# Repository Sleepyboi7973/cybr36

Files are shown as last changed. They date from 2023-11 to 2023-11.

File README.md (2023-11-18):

# cybr36
 The cybr36 is a no frills, wireless, 36 key, column-staggered keyboard sporting button cell batteries and nice!nano controllers.

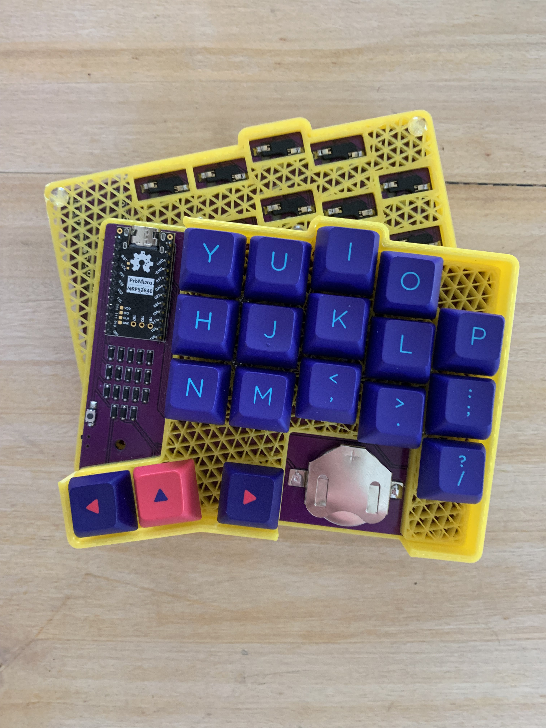
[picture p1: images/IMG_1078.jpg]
keyboard
<br>

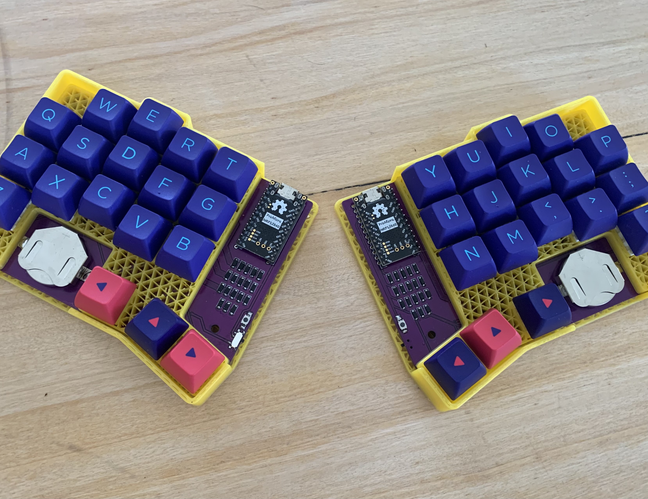
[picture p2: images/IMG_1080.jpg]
but now both of them
<br>

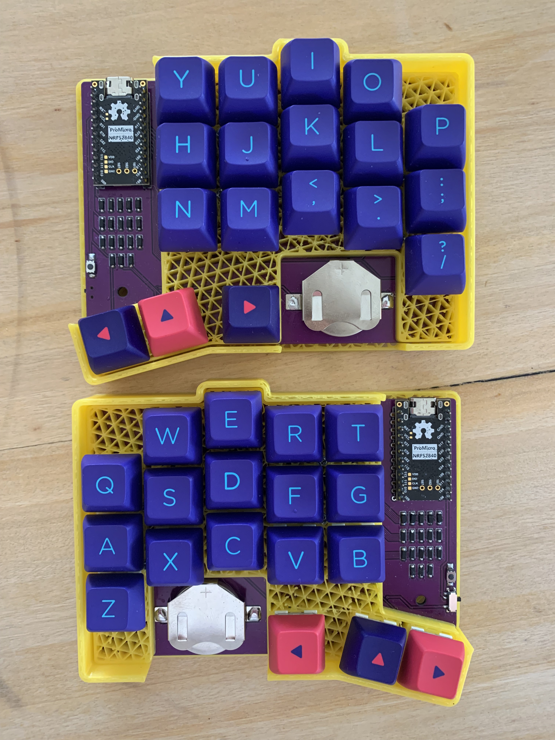
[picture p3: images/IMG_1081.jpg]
both again
<br>

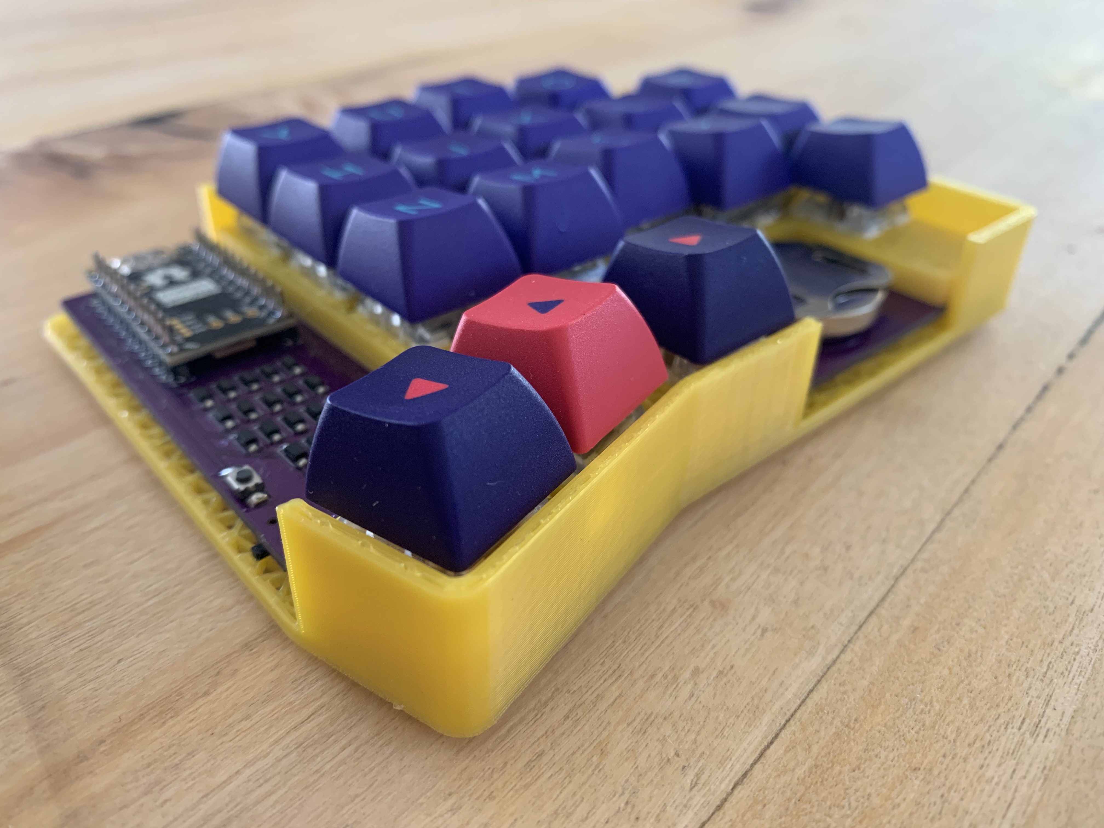
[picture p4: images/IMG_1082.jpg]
now just one
<br>

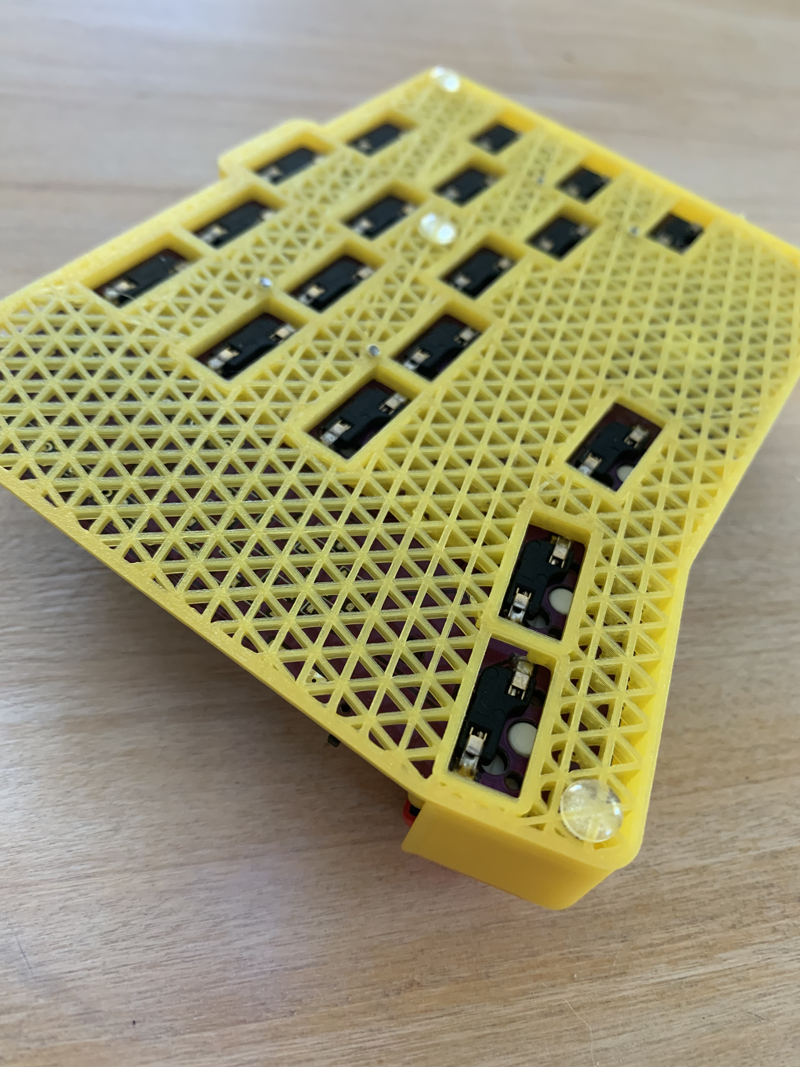
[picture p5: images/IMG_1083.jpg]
the back of just one
<br>

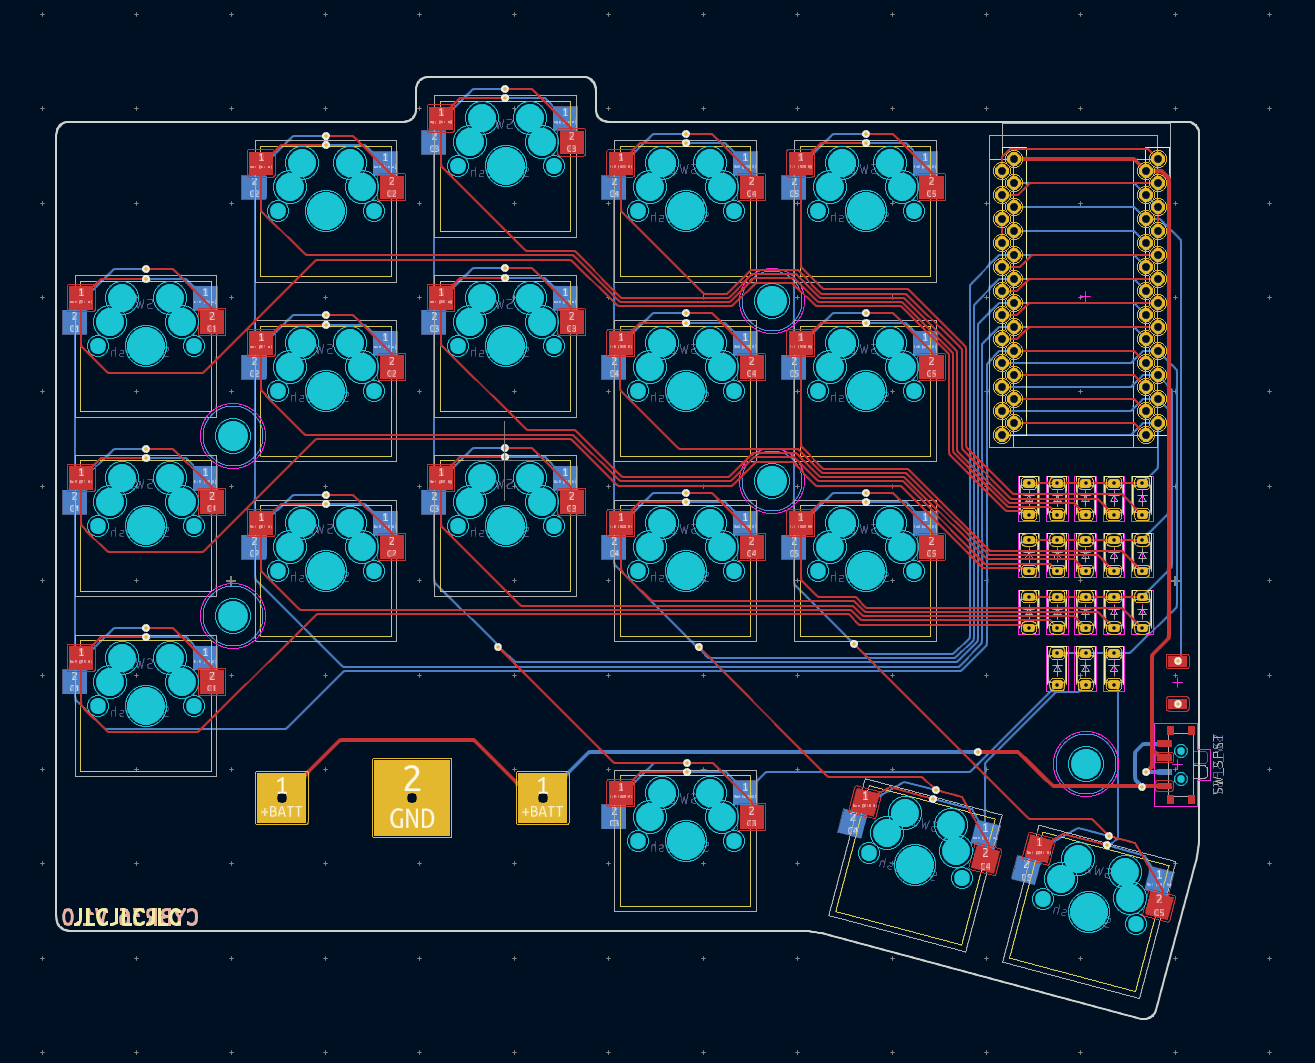
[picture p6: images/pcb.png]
pcb
<br>

## Firmware
The cybr36 runs ZMK firmware which can be found on my profile [here](https://github.com/Sleepyboi7973/zmk-config-cybr36).

## Case Printing Tips
Print the plate at 100% size and the case at 101.5% size to ensure that the pcb and plate fit inside without issue. I printed my case with no top or bottom layers, no supports, and triangular infill at 30%

## Build Guide

### Bill of Materials:
| BOM | |
|---|----|
| PCB | 2  |
| Plate | 2  |
| Case | 2  |
| Rubber Feet | 10 |
| 10mm M2 Screw | 8  |
| nice!nano V2 | 2  |
| 1x12 Pin Header | 4  |
| MX Switches | 36 |
| MX 1u Keycaps | 36 |
| MX Hotswap Sockets | 36 |
| SOD-123 1N4148 Diodes | 36 |
| PCM12/MSK12 SMD Slide Switch | 2  |
| 3x4x2mm 2 Pin SMD Button | 2  |
| 2430 Battery Holder | 2  |
| 2430 Battery | 2  |

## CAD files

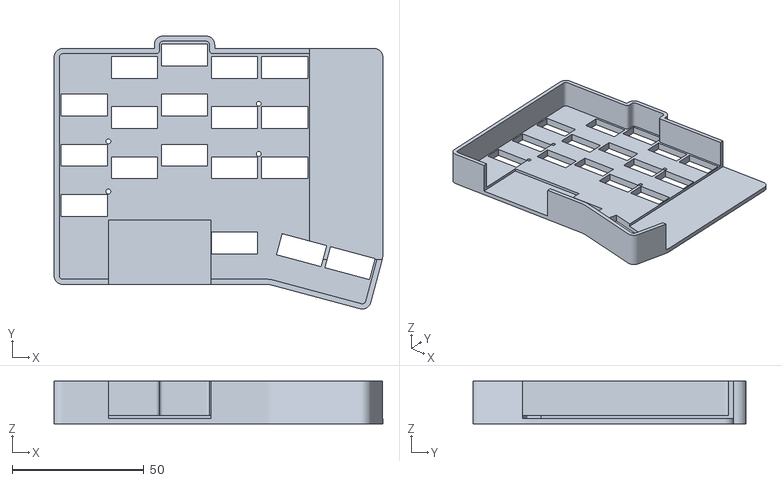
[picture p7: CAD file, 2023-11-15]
Case/CYBR36 Case.stl
125.0 x 103.8 x 16.3

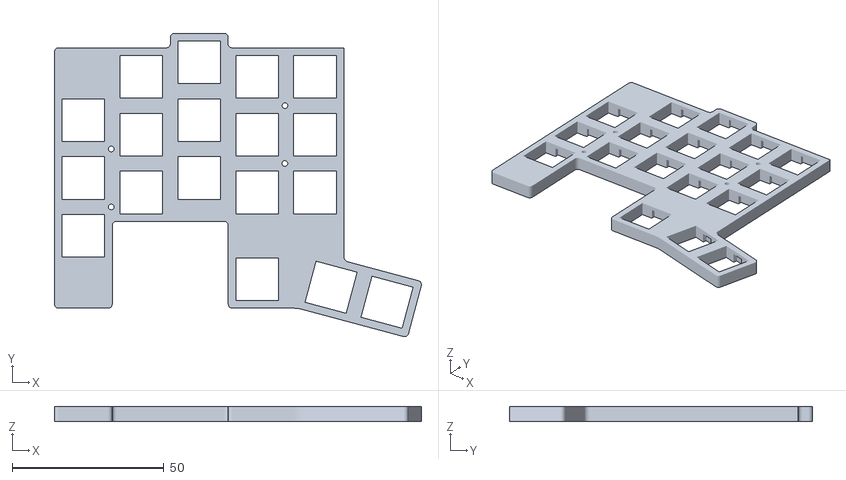
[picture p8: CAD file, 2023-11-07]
Case/CYBR36 Plate.stl
120.7 x 99.8 x 5.00

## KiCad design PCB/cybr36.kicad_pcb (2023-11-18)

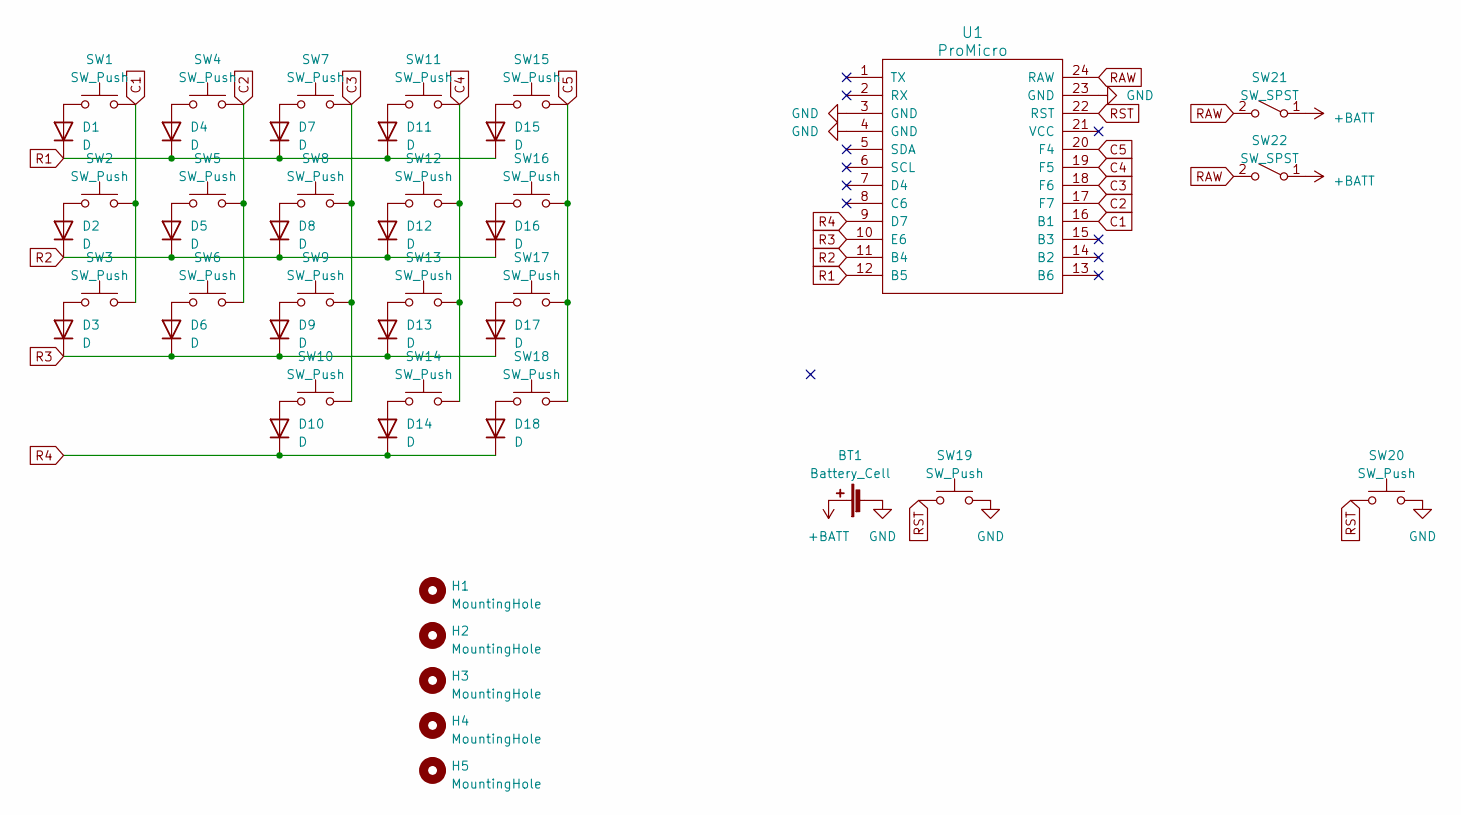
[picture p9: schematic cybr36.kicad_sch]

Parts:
BT1: Battery_Cell; 2430Holder
D1, D2, D3, D4, D5, D6, D7, D8, D9, D10, D11, D12, D13, D14, D15, D16, D17, D18: D; SOD123_DUALSIDE
H1, H2, H3, H4, H5: MountingHole; MountingHole_3.2mm_M3
SW1, SW2, SW3, SW4, SW5, SW6, SW7, SW8, SW9, SW10, SW11, SW12, SW13, SW14, SW15, SW16, SW17, SW18: SW_Push; MXReversible
SW19, SW20: SW_Push; RSTbutton
SW21, SW22: SW_SPST; SW_SPDT_PCM12
U1: ProMicro; ProMicro_v2

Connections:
+BATT: BT1.1 (+), SW21.1 (A), SW22.1 (A)
C1: SW1.2, SW2.2, SW3.2, U1.16 (B1)
C2: SW4.2, SW5.2, SW6.2, U1.17 (F7)
C3: SW7.2, SW8.2, SW9.2, SW10.2, U1.18 (F6)
C4: SW11.2, SW12.2, SW13.2, SW14.2, U1.19 (F5)
C5: SW15.2, SW16.2, SW17.2, SW18.2, U1.20 (F4)
GND: BT1.2 (-), SW19.2, SW20.2, U1.3 (GND), U1.4 (GND), U1.23 (GND)
unnamed: D1.2 (A), SW1.1
unnamed: D2.2 (A), SW2.1
unnamed: D3.2 (A), SW3.1
unnamed: D4.2 (A), SW4.1
unnamed: D5.2 (A), SW5.1
unnamed: D6.2 (A), SW6.1
unnamed: D7.2 (A), SW7.1
unnamed: D8.2 (A), SW8.1
unnamed: D9.2 (A), SW9.1
unnamed: D10.2 (A), SW10.1
unnamed: D11.2 (A), SW11.1
unnamed: D12.2 (A), SW12.1
unnamed: D13.2 (A), SW13.1
unnamed: D14.2 (A), SW14.1
unnamed: D15.2 (A), SW15.1
unnamed: D16.2 (A), SW16.1
unnamed: D17.2 (A), SW17.1
unnamed: D18.2 (A), SW18.1
R1: D1.1 (K), D4.1 (K), D7.1 (K), D11.1 (K), D15.1 (K), U1.12 (B5)
R2: D2.1 (K), D5.1 (K), D8.1 (K), D12.1 (K), D16.1 (K), U1.11 (B4)
R3: D3.1 (K), D6.1 (K), D9.1 (K), D13.1 (K), D17.1 (K), U1.10 (E6)
R4: D10.1 (K), D14.1 (K), D18.1 (K), U1.9 (D7)
RAW: SW21.2 (B), SW22.2 (B), U1.24 (RAW)
RST: SW19.1, SW20.1, U1.22 (RST)

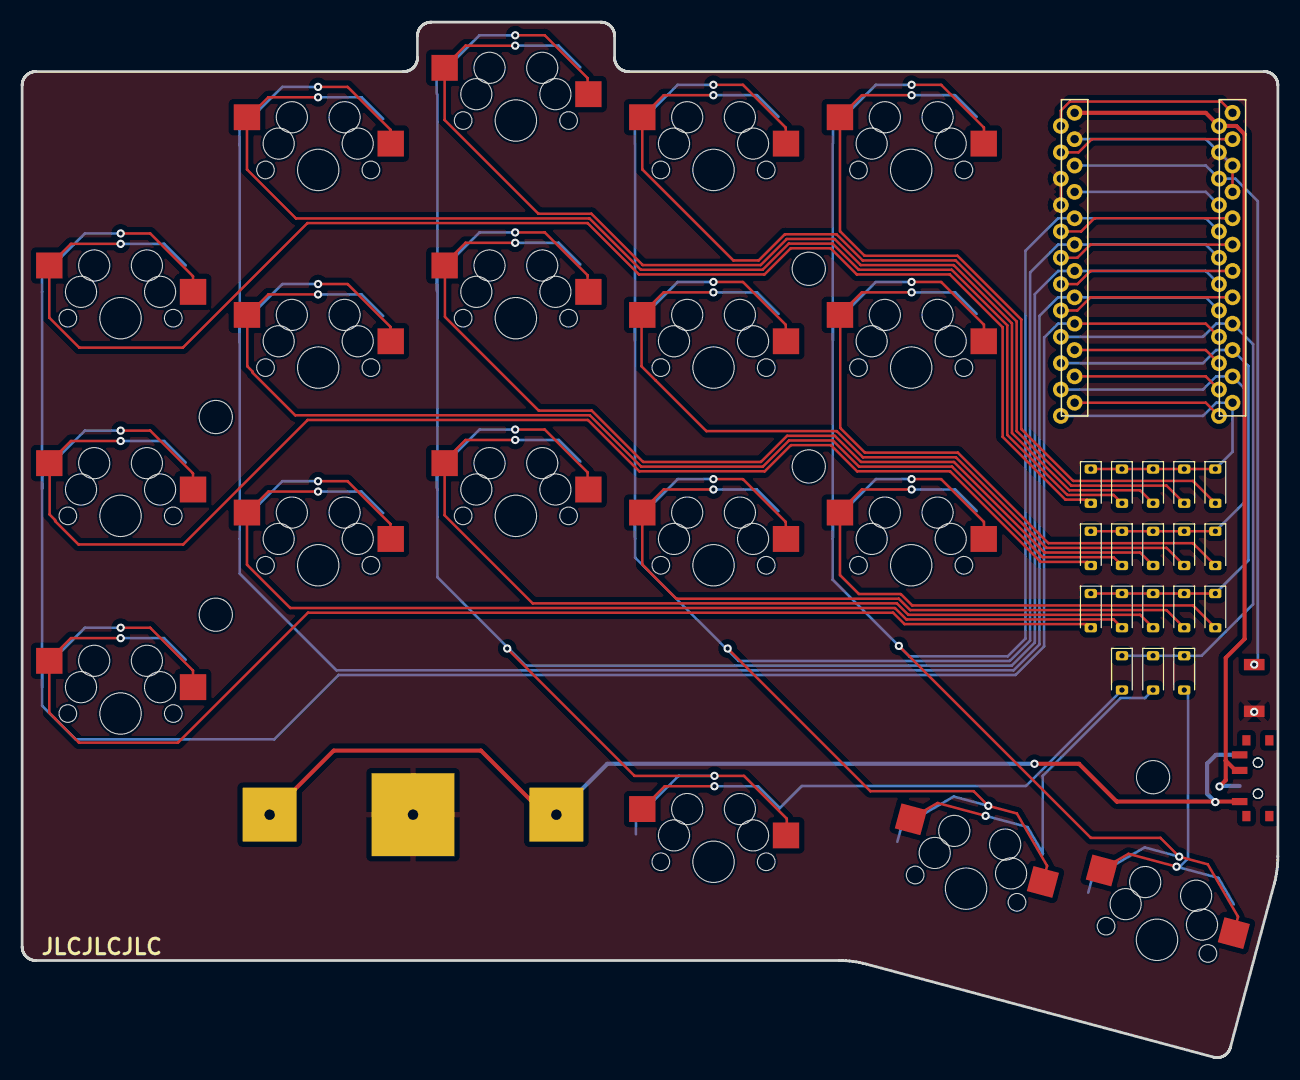
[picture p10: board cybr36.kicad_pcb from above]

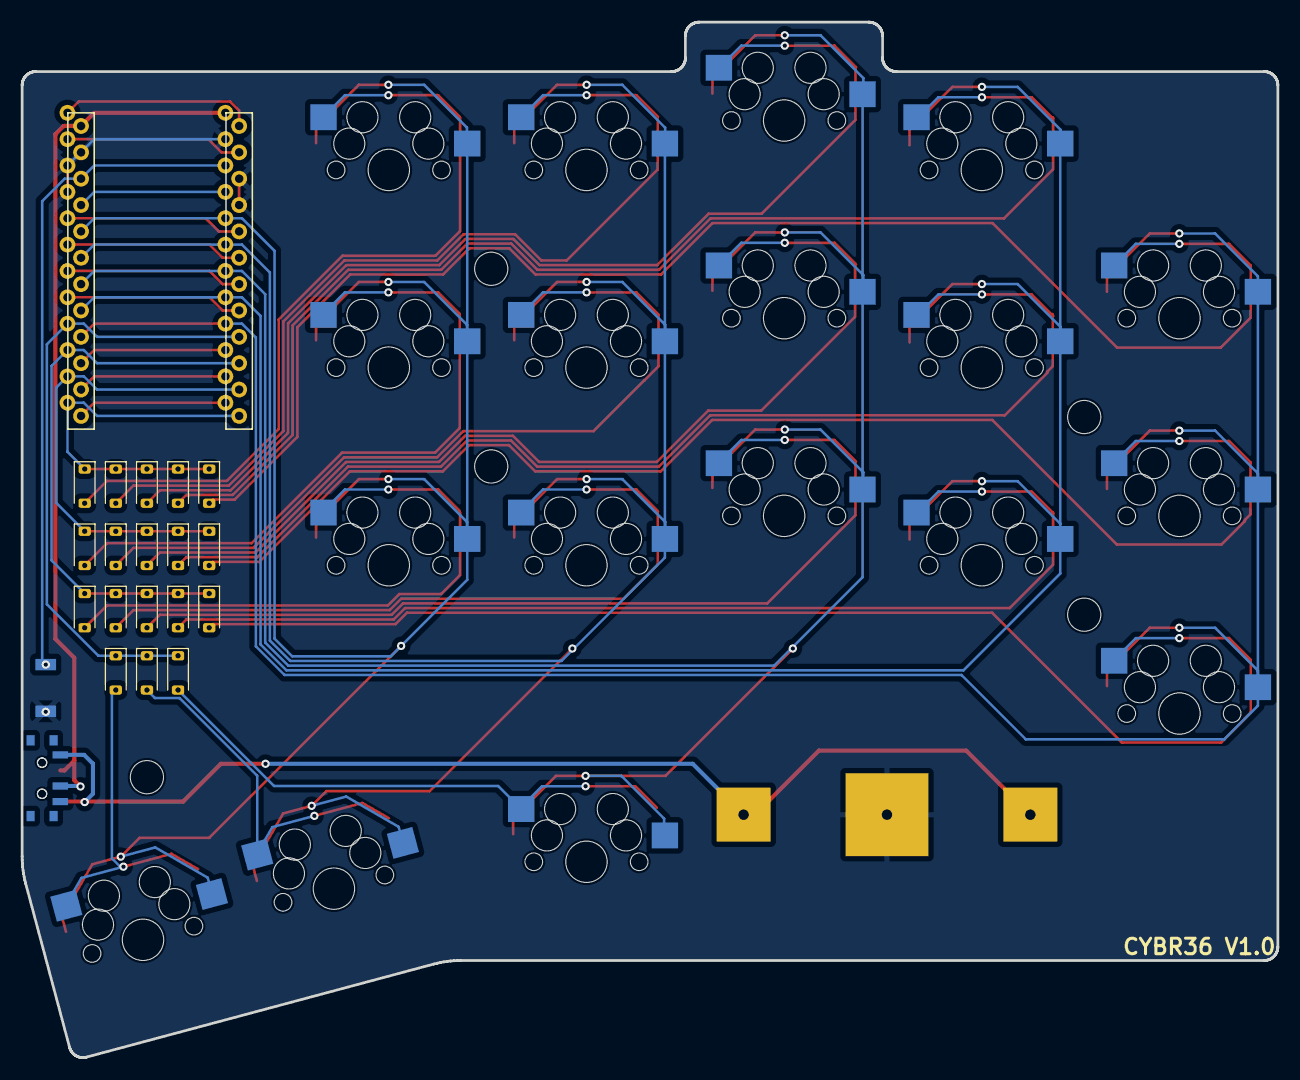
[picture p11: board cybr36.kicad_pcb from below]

Board: 2 copper layers, 121.0 x 99.8 mm, 47 parts (2 on the bottom side), 31 nets.

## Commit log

2023-11-15 case added
    [CYBR36 Case.stl]
2023-11-18 power switch added
    [cybr36.kicad_pcb, cybr36.kicad_sch]
2023-11-18 no gerber lmao
    [cybr36-B_Cu.gbr, cybr36-B_Mask.gbr, cybr36-B_Paste.gbr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]
